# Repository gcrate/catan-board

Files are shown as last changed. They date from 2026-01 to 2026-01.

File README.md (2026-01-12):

# LED Catan Board

An interactive 3D-printed Catan board with LED-lit hexes controlled by a Raspberry Pi. When you roll the dice, the matching resource hexes light up!

Roll
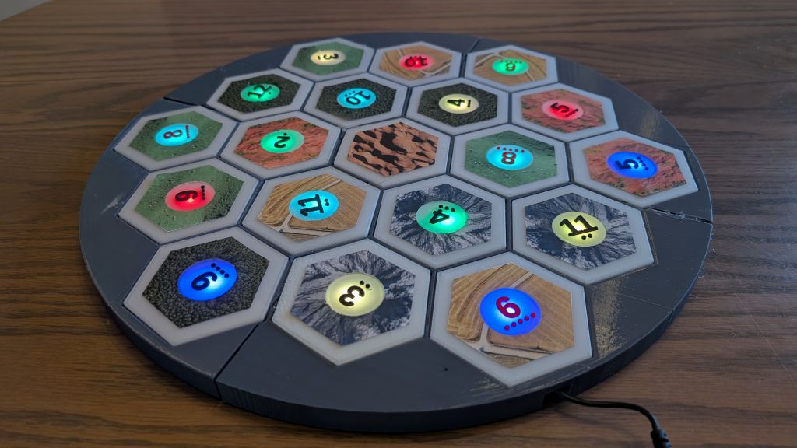
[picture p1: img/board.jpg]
Catan Board

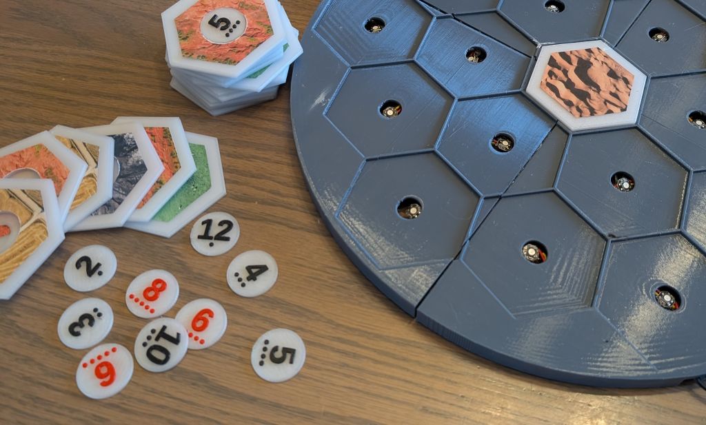
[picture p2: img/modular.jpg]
Catan Tiles


## Features

- **19 hex tiles** with satellite imagery stickers
- **18 addressable LEDs** (one per resource hex, desert has no LED)
- **Web-based controller** - access via phone or computer
- **Randomize board** with standard Catan rules
- **Auto or manual dice rolls** - matching tiles blink when rolled
- **Rainbow startup effect** until first randomization
- **Tap-to-test** individual LEDs during setup

## Hardware Required

| Item | Quantity | Notes |
|---|---|---|
| Raspberry Pi Zero W (or Zero 2 W) | 1 | Must have WiFi |
| WS2812B LED pixel modules | 18 | Individual addressable pixels with JST connectors |
| Micro SD card | 1 | 8GB+ recommended |
| USB power bank | 1 | 2A+ output recommended |
| Low Profile Micro USB cable | 1 | For powering the Pi |
| Wire | ~2m | 22-24 AWG, stranded or solid core |
| 3D printer filament | ~500g | PLA for frame and tiles |
| Clear/translucent PLA | ~50g | For number tokens |
| Printable sticker paper | 2 sheets | For hex tile imagery |

## 3D Printed Parts

All models are in the `/models` folder.

### Board (`board.3mf / board-rounded.stl`)

The main board frame with:
- 19 hex recesses for tiles
- 18 LED holes (15mm diameter) in the ledges between hexes
- Wire tunnels connecting all hexes
- Pi Zero W mounting standoffs in center
- USB cable channel

**Print Settings:**
- The full board is ~471mm diameter - too large for most printer
- board.3mf provides pre sliced / quatered board for printing on p1p/p1s
- Glue together after printing

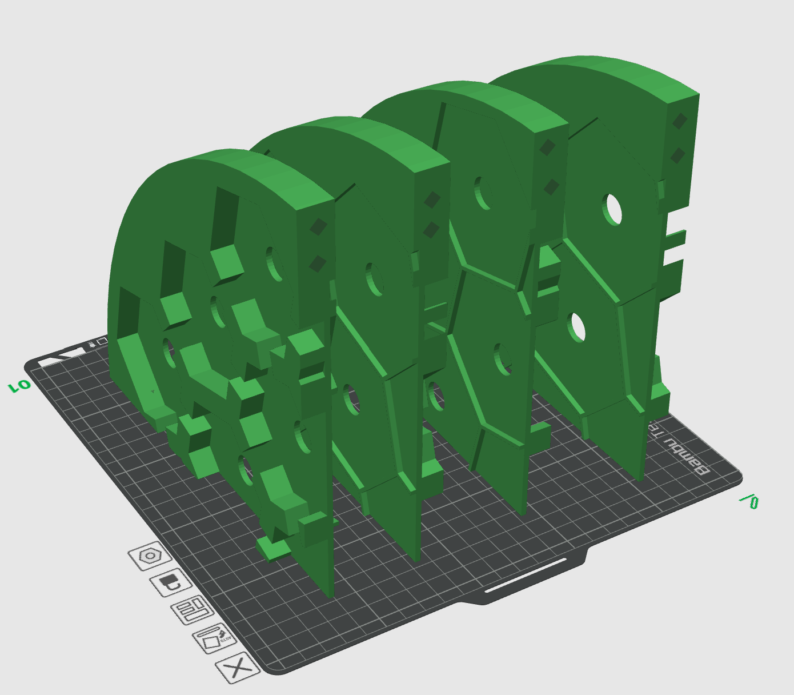
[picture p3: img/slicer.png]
In Slicer


### Hex Tiles - Desert (`tile-desert.stl`)

Central desert time, can be glued in place to hold board together

### Hex Tiles - Resources (`tile.stl`)

Print 18 resource tiles:
- 75mm flat-to-flat
- 3mm thick
- 15mm center hole for LED light
- 30mm recess for number token

### Number Tokens (`all_tokens.3mf`)

Print in clear/translucent PLA:
- 29.5mm diameter
- Raised numbers and probability dots
- Standard Catan distribution: 2, 3, 3, 4, 4, 5, 5, 6, 6, 8, 8, 9, 9, 10, 10, 11, 11, 12

## Stickers

The `/stickers` folder contains an HTML template for printing hex stickers.

1. Find satellite imagery for each resource type:
   - **Brick:** Red rock formations, clay quarries
   - **Wood:** Dense forest canopy from above
   - **Sheep:** Green pastures with sheep visible
   - **Wheat:** Golden crop fields
   - **Ore:** Mountain peaks, rocky terrain
   - **Desert:** Sand dunes

2. You can replace the images if you want to change the look `brick.jpg`, `wood.jpg`, `sheep.jpg`, `wheat.jpg`, `ore.jpg`, `desert.jpg`

3. Open `sticker-template.html` in a browser

4. Print on sticker paper at actual size (73mm hexes)

5. Cut out and apply to tiles

## Wiring

### LED Order

Wire the 18 LEDs in series, starting from the inner ring and going counter-clockwise (when looking at the bottom): 

- **Ring 1 (inner):** LED 0-5
- **Ring 2 (outer):** LED 6-17

### Connections

| LED Wire | Pi Connection |
|---|---|
| VCC (5V) | Pin 2 or 4 (5V) |
| GND | Pin 6 (Ground) |
| DIN (Data) | GPIO12 (Pin 32) |

Chain the LEDs: Pi GPIO12 → LED 0 DIN → LED 0 DOUT → LED 1 DIN → ... → LED 17

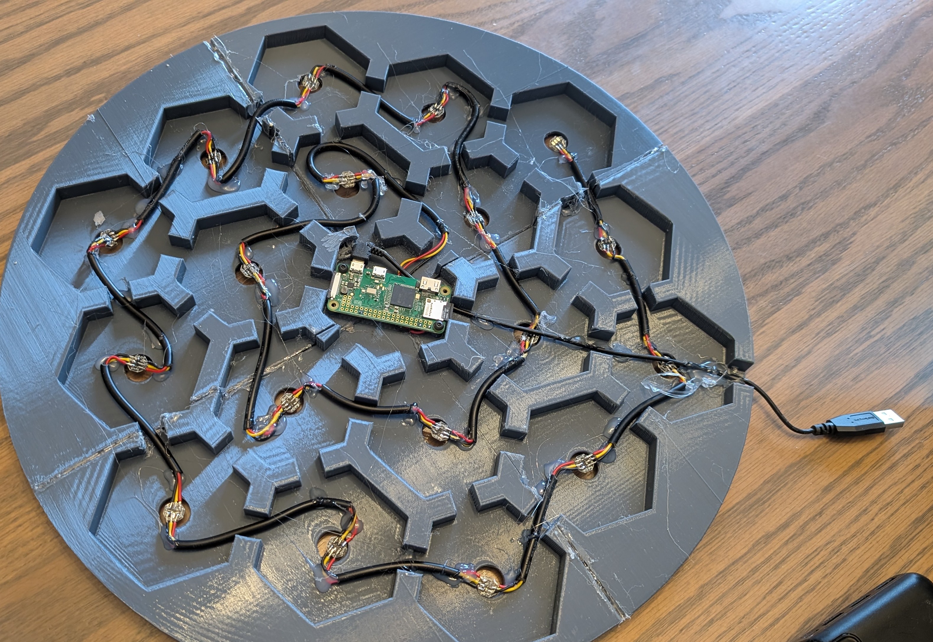
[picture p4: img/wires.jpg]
wiring


Hot glue gun the wires in place so the LEDs sit inline with the holes

## Software Setup

### 1. Flash Raspberry Pi OS

1. Download [Raspberry Pi Imager](https://www.raspberrypi.com/software/)
2. Select **Raspberry Pi OS Lite (32-bit)** under "Raspberry Pi OS (other)"
3. Click the gear icon and configure:
   - Hostname: `catan`
   - Enable SSH
   - Set username/password
   - Configure WiFi
4. Flash to SD card

### 2. Install Dependencies

SSH into your Pi:

```bash
ssh pi@catan.local
```

Update and install packages:

```bash
sudo apt update
sudo apt install -y python3-pip python3-flask git
sudo pip3 install rpi_ws281x adafruit-circuitpython-neopixel --break-system-packages
```

### 3. Clone the Repository

```bash
cd ~
git clone https://github.com/gcrate/catan-board.git
cd catan-board
```

### 4. Create Systemd Service

```bash
sudo tee /etc/systemd/system/catanboard.service > /dev/null <<EOF
[Unit]
Description=Catan Board Web Server
After=network.target

[Service]
ExecStart=/usr/bin/python3 /home/pi/catan-board/app.py
WorkingDirectory=/home/pi/catan-board
StandardOutput=inherit
StandardError=inherit
Restart=always
User=root

[Install]
WantedBy=multi-user.target
EOF
```

**Note:** Change `/home/pi/` to `/home/yourusername/` if you used a different username.

### 5. Enable and Start

```bash
sudo systemctl daemon-reload
sudo systemctl enable catanboard
sudo systemctl start catanboard
```

### 6. Access the Web Interface

Open a browser and go to:
```
http://catan.local
```

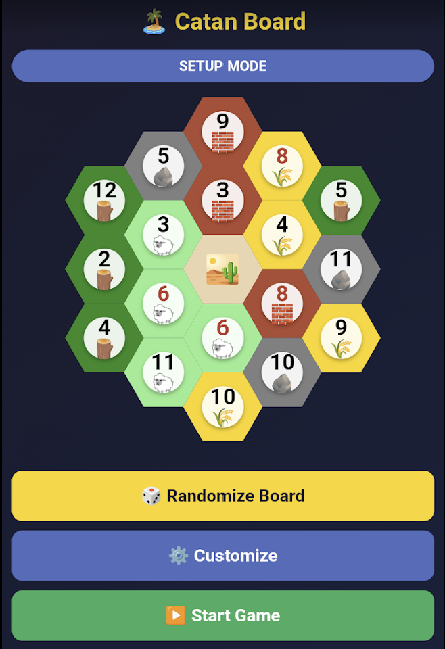
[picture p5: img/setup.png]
App setup mode

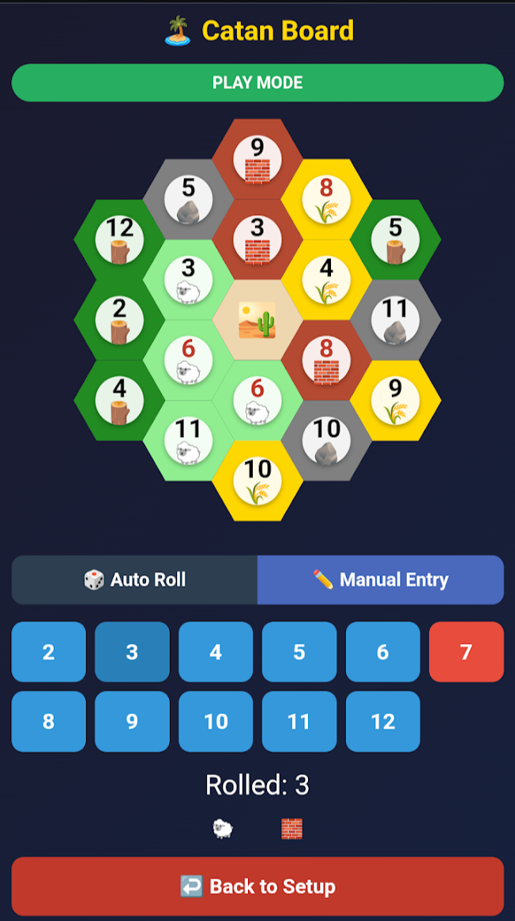
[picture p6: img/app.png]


## Usage

### Setup Mode

1. **Rainbow effect** plays on startup
2. Tap **Randomize Board** to generate a valid Catan layout
3. The LEDs will light up with resource colors
4. Tap any hex to flash that LED (for testing)
5. Use **Customize** to adjust resource counts or enable "prevent adjacent 6 & 8"
6. Tap **Start Game** when ready

### Play Mode

Two options for dice rolls:

**Auto Roll:**
- Tap **Roll Dice** to simulate 2d6
- Matching hexes will blink

**Manual Entry:**
- Tap a number button (2-12)
- Use this when rolling physical dice

Tap **Back to Setup** to randomize a new board.

## Troubleshooting

### LEDs not working

1. Check GPIO pin - code uses GPIO12 (Pin 32)
2. Verify ground is connected between Pi and LEDs
3. Make sure data wire goes to DIN (data in), not DOUT
4. Test with a simple script:

```python
import board
import neopixel
pixels = neopixel.NeoPixel(board.D12, 18, brightness=0.5)
pixels.fill((255, 0, 0))  # All red
```

### Web interface not loading

```bash
sudo systemctl status catanboard
sudo journalctl -u catanboard -n 50
```

### Wrong LEDs lighting up

The LED index must match the wiring order. Use setup mode's tap-to-flash feature to verify each position.

## Optional: Hotspot Mode

To use the board without a WiFi network, configure the Pi as a hotspot:

```bash
sudo apt install -y hostapd dnsmasq
```

See [Raspberry Pi hotspot documentation](https://www.raspberrypi.com/documentation/computers/configuration.html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) for full setup.

## TODO: 

Need to add some stickers for the ports. Using the cardboard ones that come with the game for now

## License

MIT License - feel free to build your own and modify!

## Acknowledgments

This was a quick weekend project - thanks to Claude AI!

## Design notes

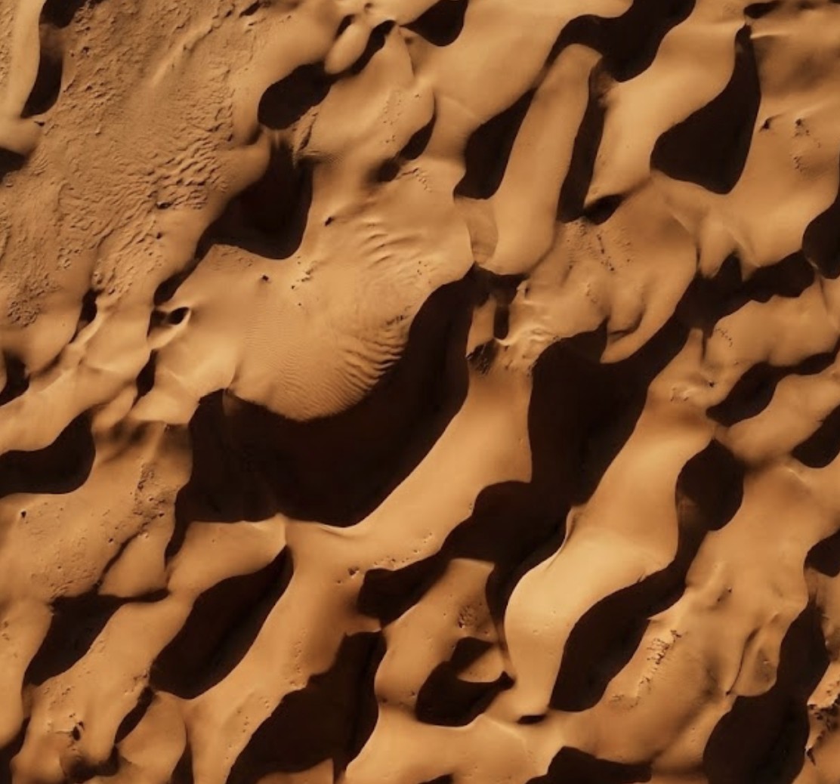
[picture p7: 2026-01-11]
stickers/desert.jpg

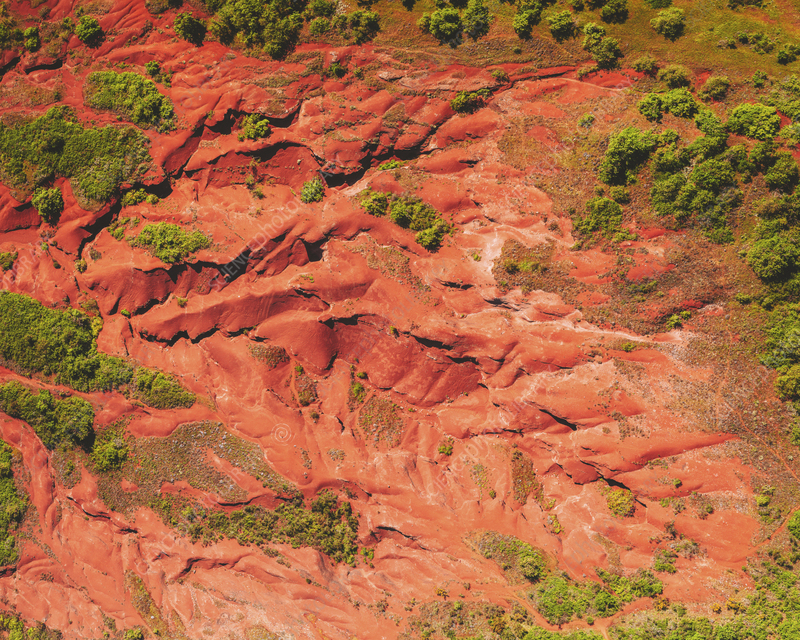
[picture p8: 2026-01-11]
stickers/brick.jpg

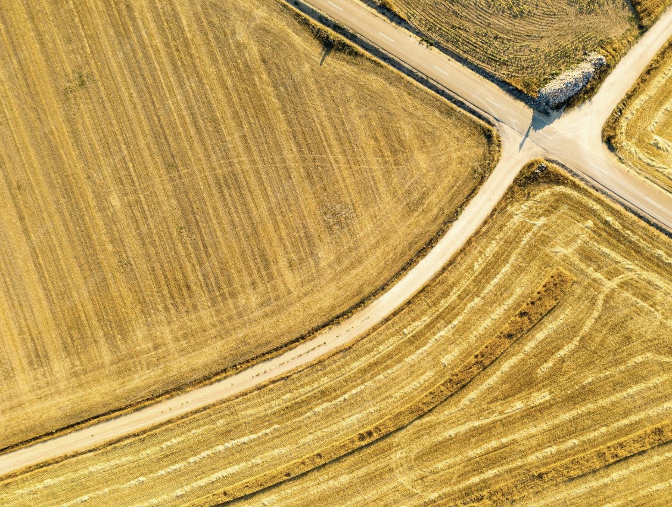
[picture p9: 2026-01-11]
stickers/wheat.jpg

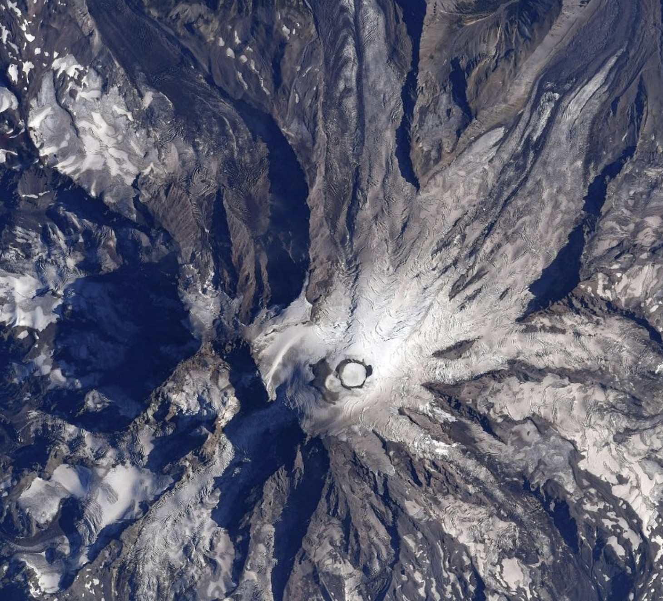
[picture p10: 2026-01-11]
stickers/ore.jpg

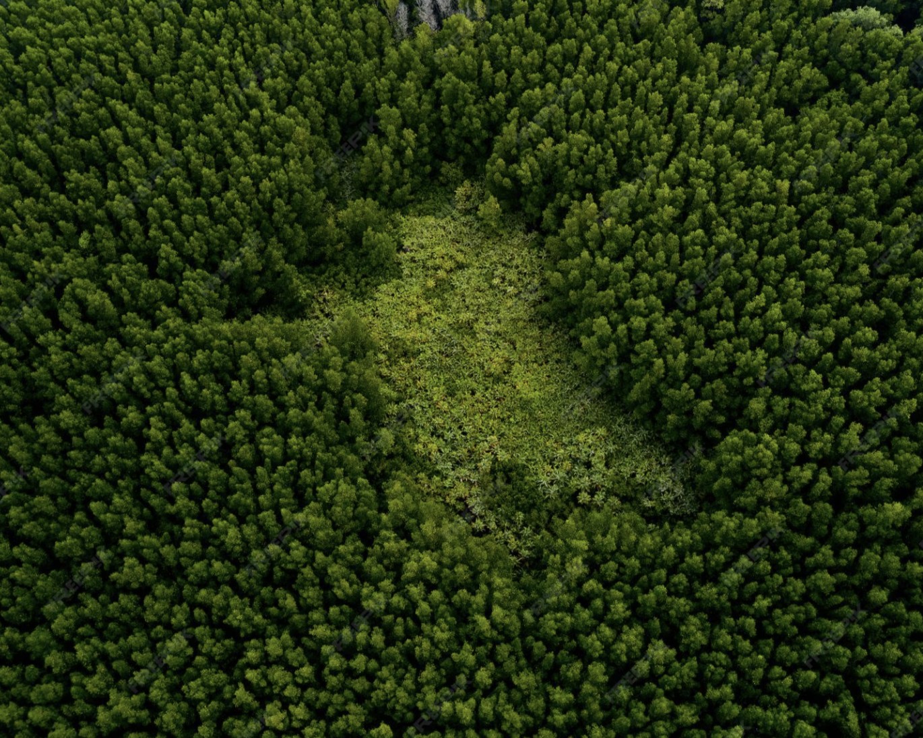
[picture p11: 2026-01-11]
stickers/wood.jpg

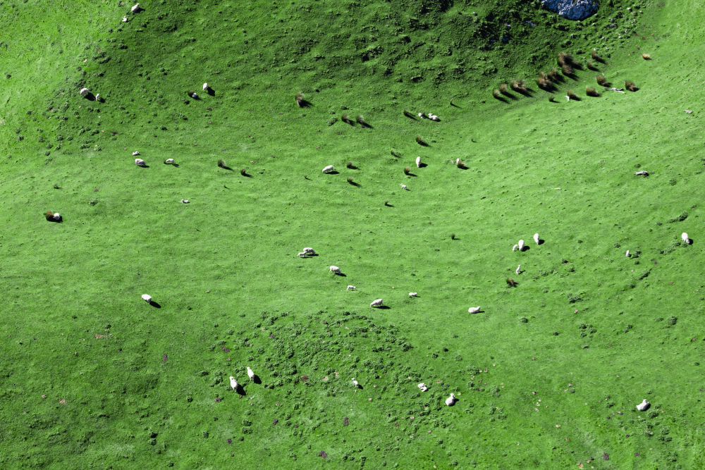
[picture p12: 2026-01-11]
stickers/sheep.jpg

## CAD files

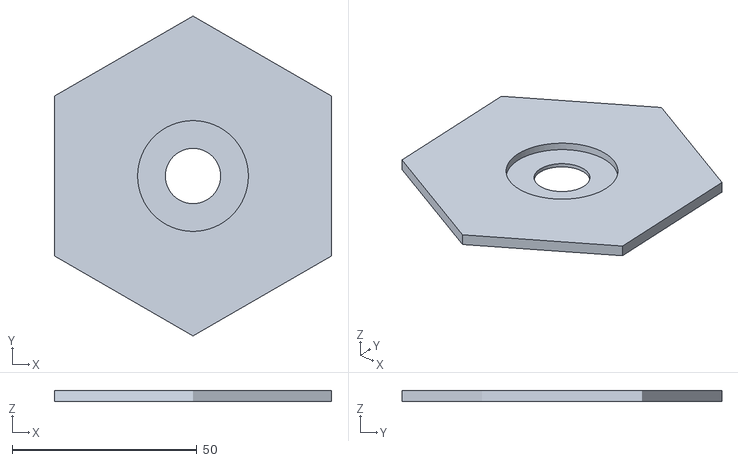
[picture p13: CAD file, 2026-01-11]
models/tile.stl
75.0 x 86.6 x 3.00

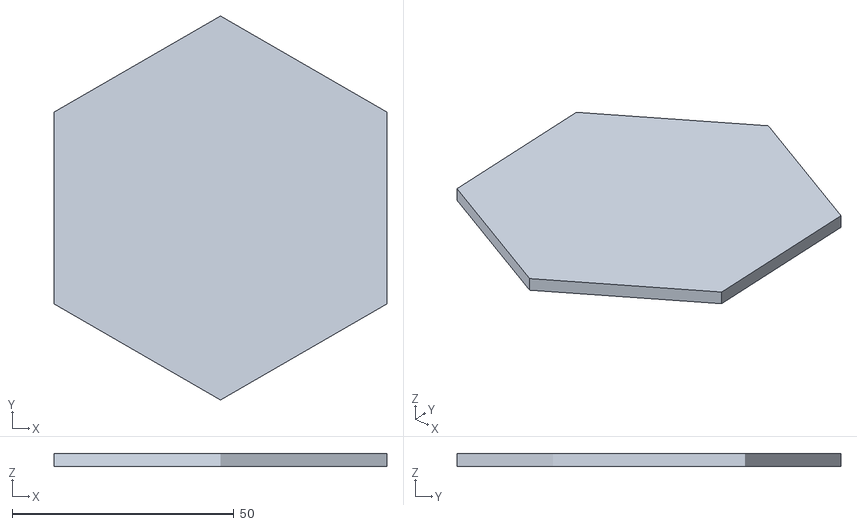
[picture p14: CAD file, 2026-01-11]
models/tile-desert.stl
75.0 x 86.6 x 3.00

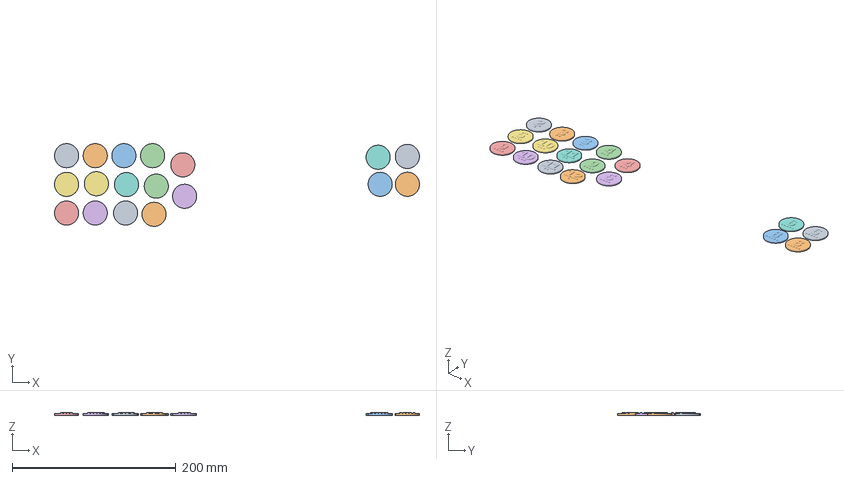
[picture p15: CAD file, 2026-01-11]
models/all_tokens.3mf
445.7 x 101.1 x 3.20 mm
all_tokens.stl_1
all_tokens.stl_2
all_tokens.stl_3
all_tokens.stl_4
all_tokens.stl_5
all_tokens.stl_6
all_tokens.stl_7
all_tokens.stl_8
all_tokens.stl_9
all_tokens.stl_10
all_tokens.stl_11
all_tokens.stl_12
all_tokens.stl_13
all_tokens.stl_14
all_tokens.stl_15
all_tokens.stl_16
all_tokens.stl_17
all_tokens.stl_18

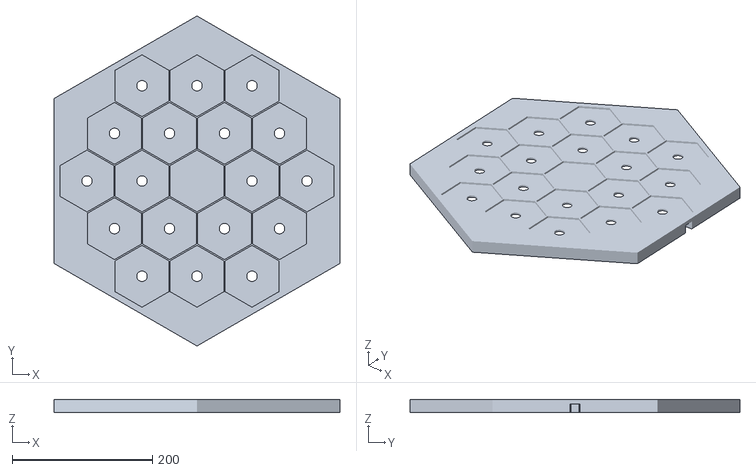
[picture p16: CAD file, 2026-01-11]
models/board-original.stl
407.9 x 471.0 x 18.0

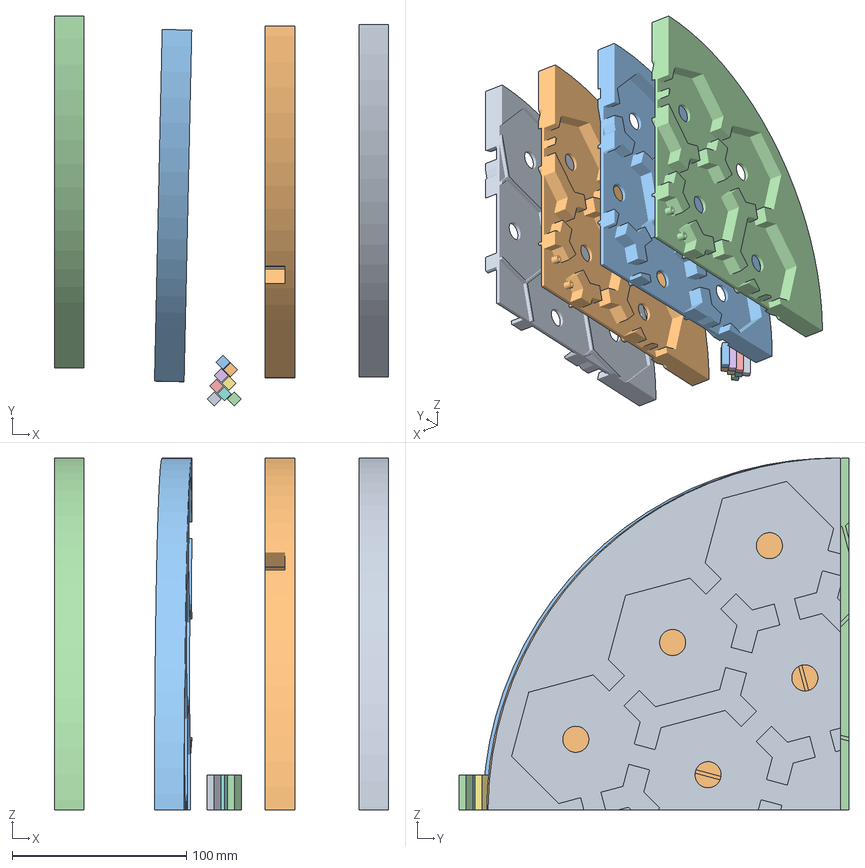
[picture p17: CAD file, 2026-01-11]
models/board.3mf
191.7 x 223.6 x 201.8 mm
Epic Allis-Wluff.stl_A_B
Epic Allis-Wluff.stl_A_A
Epic Allis-Wluff.stl_B_B
Epic Allis-Wluff.stl_B_A
Epic Allis-Wluff.stl_A-Dowel-Connector-7
Epic Allis-Wluff.stl_A-Dowel-Connector-8
Epic Allis-Wluff.stl-Dowel-Connector-1
Epic Allis-Wluff.stl-Dowel-Connector-2
Epic Allis-Wluff.stl-Dowel-Connector-3
Epic Allis-Wluff.stl-Dowel-Connector-4
Epic Allis-Wluff.stl_B-Dowel-Connector-5
Epic Allis-Wluff.stl_B-Dowel-Connector-6

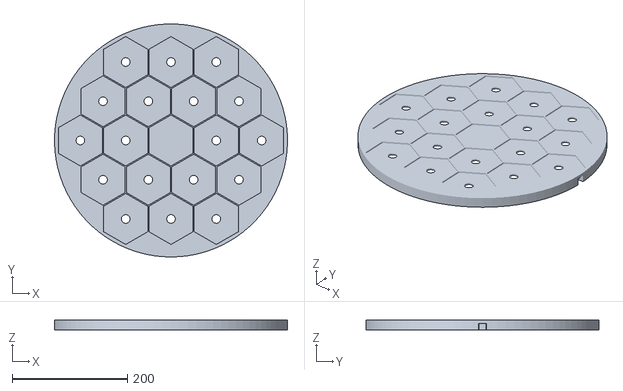
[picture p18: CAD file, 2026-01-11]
models/board-rounded.stl
403.7 x 403.6 x 17.0

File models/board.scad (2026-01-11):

// Catan Board Parameters
hex_flat_to_flat = 75;
tile_tolerance = 1.5;
led_hole_diameter = 15;
frame_depth = 18;
recess_depth = 3;
ledge_thickness = 3;
ledge_width = 6;

// Wire tunnel parameters
tunnel_width = 12;

// USB channel parameters
usb_channel_width = 14;
usb_channel_height = 12;

// Pi Zero W mounting parameters
pi_hole_spacing_x = 58;
pi_hole_spacing_y = 23;
pi_standoff_diameter = 6;
pi_screw_hole_diameter = 2.5;
pi_standoff_height = 6;

// Derived values
hex_radius = (hex_flat_to_flat + tile_tolerance) / 2 / cos(30);
cavity_radius = hex_radius - ledge_width;
cavity_depth = frame_depth - recess_depth - ledge_thickness;
hex_spacing = hex_flat_to_flat + tile_tolerance + 2;
outer_radius = hex_spacing * 3;

// Cut for a single hex with LED hole
module hex_cut_base() {
    rotate([0, 0, 30]) {
        translate([0, 0, frame_depth - recess_depth])
            cylinder(r = hex_radius, h = recess_depth + 1, $fn = 6);
        translate([0, 0, -1])
            cylinder(r = cavity_radius, h = cavity_depth + 1, $fn = 6);
        translate([0, 0, cavity_depth - 1])
            cylinder(d = led_hole_diameter, h = ledge_thickness + 2, $fn = 32);
    }
}

// Center hex - no LED hole, Pi goes here
module center_hex_cut() {
    rotate([0, 0, 30]) {
        translate([0, 0, frame_depth - recess_depth])
            cylinder(r = hex_radius, h = recess_depth + 1, $fn = 6);
        translate([0, 0, -1])
            cylinder(r = cavity_radius, h = cavity_depth + 1, $fn = 6);
    }
}

// Pi mounting standoff
module pi_standoff() {
    difference() {
        cylinder(d = pi_standoff_diameter, h = pi_standoff_height, $fn = 32);
        translate([0, 0, -1])
            cylinder(d = pi_screw_hole_diameter, h = pi_standoff_height + 2, $fn = 32);
    }
}

module pi_standoffs() {
    for (x = [-pi_hole_spacing_x/2, pi_hole_spacing_x/2]) {
        for (y = [-pi_hole_spacing_y/2, pi_hole_spacing_y/2]) {
            translate([x, y, cavity_depth - pi_standoff_height])
                pi_standoff();
        }
    }
}

// USB channel
module usb_channel() {
    translate([0, -usb_channel_width/2, -1])
        cube([hex_spacing * 3, usb_channel_width, usb_channel_height + 1]);
}

// Tunnel cut between two hexes
module tunnel_cut(from_q, from_r, to_q, to_r) {
    from_x = hex_spacing * (from_q + from_r/2);
    from_y = hex_spacing * from_r * sin(60);
    to_x = hex_spacing * (to_q + to_r/2);
    to_y = hex_spacing * to_r * sin(60);
    mid_x = (from_x + to_x) / 2;
    mid_y = (from_y + to_y) / 2;
    angle = atan2(to_y - from_y, to_x - from_x);
    translate([mid_x, mid_y, -1])
        rotate([0, 0, angle])
        translate([-10, -tunnel_width/2, 0])
            cube([20, tunnel_width, cavity_depth + 1]);
}

module place_hex_cut(q, r) {
    x = hex_spacing * (q + r/2);
    y = hex_spacing * r * sin(60);
    translate([x, y, 0])
        hex_cut_base();
}

// Base plate
module base_plate() {
    rotate([0, 0, 30])
    cylinder(r = outer_radius, h = frame_depth, $fn = 6);
}

// Full board
module full_board() {
    union() {
        difference() {
            base_plate();
            center_hex_cut();
            usb_channel();
            
            // Ring 1
            place_hex_cut(1, 0);
            place_hex_cut(0, 1);
            place_hex_cut(-1, 1);
            place_hex_cut(-1, 0);
            place_hex_cut(0, -1);
            place_hex_cut(1, -1);
            
            // Ring 2
            place_hex_cut(2, 0);
            place_hex_cut(1, 1);
            place_hex_cut(0, 2);
            place_hex_cut(-1, 2);
            place_hex_cut(-2, 2);
            place_hex_cut(-2, 1);
            place_hex_cut(-2, 0);
            place_hex_cut(-1, -1);
            place_hex_cut(0, -2);
            place_hex_cut(1, -2);
            place_hex_cut(2, -2);
            place_hex_cut(2, -1);
            
            // Tunnels - center to ring 1
            tunnel_cut(0, 0, 1, 0);
            tunnel_cut(0, 0, 0, 1);
            tunnel_cut(0, 0, -1, 1);
            tunnel_cut(0, 0, -1, 0);
            tunnel_cut(0, 0, 0, -1);
            tunnel_cut(0, 0, 1, -1);
            
            // Tunnels - ring 1 around
            tunnel_cut(1, 0, 0, 1);
            tunnel_cut(0, 1, -1, 1);
            tunnel_cut(-1, 1, -1, 0);
            tunnel_cut(-1, 0, 0, -1);
            tunnel_cut(0, -1, 1, -1);
            tunnel_cut(1, -1, 1, 0);
            
            // Tunnels - ring 1 to ring 2
            tunnel_cut(1, 0, 2, 0);
            tunnel_cut(1, 0, 2, -1);
            tunnel_cut(0, 1, 1, 1);
            tunnel_cut(0, 1, 0, 2);
            tunnel_cut(-1, 1, -1, 2);
            tunnel_cut(-1, 1, -2, 2);
            tunnel_cut(-1, 0, -2, 1);
            tunnel_cut(-1, 0, -2, 0);
            tunnel_cut(0, -1, -1, -1);
            tunnel_cut(0, -1, 0, -2);
            tunnel_cut(1, -1, 1, -2);
            tunnel_cut(1, -1, 2, -2);
            
            // Tunnels - ring 2 around
            tunnel_cut(2, 0, 1, 1);
            tunnel_cut(1, 1, 0, 2);
            tunnel_cut(0, 2, -1, 2);
            tunnel_cut(-1, 2, -2, 2);
            tunnel_cut(-2, 2, -2, 1);
            tunnel_cut(-2, 1, -2, 0);
            tunnel_cut(-2, 0, -1, -1);
            tunnel_cut(-1, -1, 0, -2);
            tunnel_cut(0, -2, 1, -2);
            tunnel_cut(1, -2, 2, -2);
            tunnel_cut(2, -2, 2, -1);
            tunnel_cut(2, -1, 2, 0);
        }
        pi_standoffs();
    }
}

full_board();

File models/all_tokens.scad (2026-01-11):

// Catan Number Tokens - All tokens for a standard game
// Print in clear/translucent PLA
// Standard set: 2, 3, 3, 4, 4, 5, 5, 6, 6, 8, 8, 9, 9, 10, 10, 11, 11, 12

// Token parameters
token_diameter = 29.5;
token_thickness = 2;
number_height = 1.2;  // How high the number is raised
number_size = 14;

// Layout
spacing = 35;

// Probability dots
function get_dots(n) = 
    (n == 2 || n == 12) ? 1 :
    (n == 3 || n == 11) ? 2 :
    (n == 4 || n == 10) ? 3 :
    (n == 5 || n == 9) ? 4 :
    (n == 6 || n == 8) ? 5 : 0;

dot_diameter = 2.5;
dot_spacing = 4;
dot_y_offset = -8;

module number_token(number) {
    // Base token
    cylinder(d = token_diameter, h = token_thickness, $fn = 64);
    
    // Raised number
    translate([0, 2, token_thickness])
        linear_extrude(height = number_height)
            text(str(number), size = number_size, font = "Liberation Sans:style=Bold", halign = "center", valign = "center");
    
    // Raised dots
    num_dots = get_dots(number);
    if (num_dots > 0) {
        start_x = -(num_dots - 1) * dot_spacing / 2;
        for (i = [0:num_dots-1]) {
            translate([start_x + i * dot_spacing, dot_y_offset, token_thickness])
                cylinder(d = dot_diameter, h = number_height, $fn = 16);
        }
    }
}

// Standard Catan number distribution
numbers = [2, 3, 3, 4, 4, 5, 5, 6, 6, 8, 8, 9, 9, 10, 10, 11, 11, 12];

// Arrange in a grid (6 columns)
cols = 6;
for (i = [0:len(numbers)-1]) {
    row = floor(i / cols);
    col = i % cols;
    translate([col * spacing, -row * spacing, 0])
        number_token(numbers[i]);
}

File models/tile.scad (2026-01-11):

// Catan Hex Tile
// Designed for sticker top and translucent number token

// Tile parameters - should match frame recess
tile_flat_to_flat = 75;
tile_thickness = 3;

// Light hole parameters
light_hole_diameter = 15;

// Token recess parameters
token_diameter = 30;
token_recess_depth = 2;

// Derived values
tile_radius = tile_flat_to_flat / 2 / cos(30);

module hex_tile() {
    difference() {
        // Main hex body
        rotate([0, 0, 30])
            cylinder(r = tile_radius, h = tile_thickness, $fn = 6);
        
        // Light hole through center
        translate([0, 0, -1])
            cylinder(d = light_hole_diameter, h = tile_thickness + 2, $fn = 32);
        
        // Token recess on top
        translate([0, 0, tile_thickness - token_recess_depth])
            cylinder(d = token_diameter, h = token_recess_depth + 1, $fn = 64);
    }
}

hex_tile();

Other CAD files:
models/all_tokens.stl

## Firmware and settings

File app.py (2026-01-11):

from flask import Flask, render_template, jsonify, request
import random
import json
import threading
import time

app = Flask(__name__)

# LED control - will be replaced with real implementation when hardware is ready
LED_ENABLED = True
pixels = None

if LED_ENABLED:
    import board
    import neopixel
    pixels = neopixel.NeoPixel(board.D12, 18, brightness=0.5, auto_write=False)

# Resource colors (RGB)
RESOURCE_COLORS = {
    'brick': (130, 3, 3),      # Brownish red
    'wood': (0, 120, 0),        # Dark green
    'sheep': (0, 100, 30),    # Light green
    'wheat': (130, 85, 0),      # Gold
    'ore': (10, 10, 128),      # Gray
    'desert': (0, 0, 0)          # No light for desert (always center, no LED)
}

# Standard Catan resource distribution (18 resources + 1 desert in center = 19)
# Desert is always in center (index 0) and has no LED
STANDARD_RESOURCES = {
    'brick': 3,
    'wood': 4,
    'sheep': 4,
    'wheat': 4,
    'ore': 3
}
# Note: desert is not in this dict - it's always fixed at center

# Standard Catan number tokens (no 7, desert gets none)
STANDARD_NUMBERS = [2, 3, 3, 4, 4, 5, 5, 6, 6, 8, 8, 9, 9, 10, 10, 11, 11, 12]

# Hex positions (index corresponds to LED index)
# Adjacency map for checking 6/8 rule
ADJACENCIES = {
    0: [1, 2, 3, 4, 5, 6],      # Center connects to ring 1
    1: [0, 2, 6, 7, 8, 12],     # Ring 1
    2: [0, 1, 3, 8, 9, 10],
    3: [0, 2, 4, 10, 11, 12],
    4: [0, 3, 5, 12, 13, 14],
    5: [0, 4, 6, 14, 15, 16],
    6: [0, 1, 5, 16, 17, 7],
    7: [1, 6, 8, 17, 18, 12],   # Ring 2
    8: [1, 2, 7, 9, 18, 19],
    9: [2, 8, 10, 19, 20, 21],
    10: [2, 3, 9, 11, 21, 22],
    11: [3, 10, 12, 22, 23, 24],
    12: [1, 3, 4, 7, 11, 13],
    13: [4, 12, 14, 24, 25, 26],
    14: [4, 5, 13, 15, 26, 27],
    15: [5, 14, 16, 27, 28, 29],
    16: [5, 6, 15, 17, 29, 30],
    17: [6, 7, 16, 18, 30, 31],
    18: [7, 8, 17, 19, 31, 32]
}

# Simplified adjacency for 19-hex board (0 = center, 1-6 = ring 1, 7-18 = ring 2)
# Re-mapping to match actual 19 hexes
ADJACENCIES_19 = {
    0: [1, 2, 3, 4, 5, 6],           # Center
    1: [0, 2, 6, 7, 8, 12],          # Ring 1
    2: [0, 1, 3, 8, 9, 10],
    3: [0, 2, 4, 10, 11, 12],
    4: [0, 3, 5, 12, 13, 14],
    5: [0, 4, 6, 14, 15, 16],
    6: [0, 1, 5, 16, 17, 7],
    7: [1, 6, 17, 18],               # Ring 2 (corners have fewer neighbors)
    8: [1, 2, 9, 7],
    9: [2, 8, 10, 18],
    10: [2, 3, 9, 11],
    11: [3, 10, 12, 18],
    12: [3, 4, 11, 13],
    13: [4, 12, 14, 18],
    14: [4, 5, 13, 15],
    15: [5, 14, 16, 18],
    16: [5, 6, 15, 17],
    17: [6, 7, 16, 18],
    18: [7, 9, 11, 13, 15, 17]       # This doesn't exist in standard - we have 19 hexes 0-18
}

# Correct adjacency for 19 hexes (center=0, ring1=1-6, ring2=7-18)
HEX_ADJACENCIES = {
    0: [1, 2, 3, 4, 5, 6],
    1: [0, 2, 6, 7, 8, 9],
    2: [0, 1, 3, 9, 10, 11],
    3: [0, 2, 4, 11, 12, 13],
    4: [0, 3, 5, 13, 14, 15],
    5: [0, 4, 6, 15, 16, 17],
    6: [0, 1, 5, 17, 18, 7],
    7: [1, 6, 8, 18],
    8: [1, 7, 9],
    9: [1, 2, 8, 10],
    10: [2, 9, 11],
    11: [2, 3, 10, 12],
    12: [3, 11, 13],
    13: [3, 4, 12, 14],
    14: [4, 13, 15],
    15: [4, 5, 14, 16],
    16: [5, 15, 17],
    17: [5, 6, 16, 18],
    18: [6, 7, 17]
}

# Current board state
board_state = {
    'tiles': [],  # List of {resource, number, led_index}
    'mode': 'setup',  # 'setup' or 'play'
    'config': {
        'resources': STANDARD_RESOURCES.copy(),
        'numbers': STANDARD_NUMBERS.copy(),
        'prevent_adjacent_68': False
    }
}

# Track which LEDs are currently flashing
flashing_leds = set()

# Track rainbow animation state
rainbow_animation_running = False

# Track red flash state (for 7 rolls)
red_flash_in_progress = False


def get_rainbow_color(hue):
    """Convert hue (0-1) to RGB color"""
    # hue: 0=red, 0.166=yellow, 0.333=green, 0.5=cyan, 0.666=blue, 0.833=magenta, 1=red
    if hue < 0 or hue > 1:
        hue = hue % 1
    
    h = hue * 6
    c = 200  # Chroma (brightness)
    
    if h < 1:
        r, g, b = c, int(c * h), 0
    elif h < 2:
        r, g, b = int(c * (2 - h)), c, 0
    elif h < 3:
        r, g, b = 0, c, int(c * (h - 2))
    elif h < 4:
        r, g, b = 0, int(c * (4 - h)), c
    elif h < 5:
        r, g, b = int(c * (h - 4)), 0, c
    else:
        r, g, b = c, 0, int(c * (6 - h))
    
    return (int(r), int(g), int(b))


def rainbow_cycle_animation():
    """Cycle all LEDs through rainbow colors"""
    global rainbow_animation_running
    
    if not LED_ENABLED or pixels is None:
        return
    
    hue = 0
    while rainbow_animation_running:
        for i in range(18):
            pixels[i] = get_rainbow_color(hue + (i / 18.0))
        pixels.show()
        hue += 0.01  # Increment hue for smooth cycling
        time.sleep(0.05)  # Update every 50ms


def init_board():
    """Initialize board with empty tiles"""
    global rainbow_animation_running
    
    board_state['tiles'] = [
        {'resource': None, 'number': None, 'led_index': i}
        for i in range(19)
    ]
    
    # Start rainbow animation
    if LED_ENABLED and pixels is not None:
        rainbow_animation_running = True
        thread = threading.Thread(target=rainbow_cycle_animation, daemon=True)
        thread.start()


def check_adjacent_68(tiles):
    """Check if any 6 and 8 are adjacent"""
    for i, tile in enumerate(tiles):
        if tile['number'] in [6, 8]:
            for adj_idx in HEX_ADJACENCIES.get(i, []):
                if adj_idx < len(tiles) and tiles[adj_idx]['number'] in [6, 8]:
                    return True
    return False


def randomize_board(config, max_attempts=100):
    """Randomize the board with given configuration"""
    global rainbow_animation_running
    
    # Stop rainbow animation
    rainbow_animation_running = False
    time.sleep(0.1)  # Give animation thread time to stop
    
    resources = config['resources']
    numbers = config['numbers'].copy()
    prevent_68 = config['prevent_adjacent_68']

    # Build resource list for the 18 non-center tiles
    resource_list = []
    for resource, count in resources.items():
        resource_list.extend([resource] * count)

    # Verify we have exactly 18 resources
    if len(resource_list) != 18:
        raise ValueError(f"Resources must add up to 18, got {len(resource_list)}")

    # Shuffle resources
    random.shuffle(resource_list)

    # Create tiles - desert always at center (index 0), no LED there
    tiles = [{'resource': 'desert', 'number': None, 'led_index': None}]  # Center

    # Add the 18 resource tiles (indices 1-18, LED indices 0-17)
    for i in range(18):
        tiles.append({
            'resource': resource_list[i],
            'number': None,
            'led_index': i  # LED 0-17 maps to tile 1-18
        })

    # Assign numbers to non-desert tiles (indices 1-18)
    for attempt in range(max_attempts):
        random.shuffle(numbers)
        number_list = numbers.copy()

        for i in range(1, 19):
            tiles[i]['number'] = number_list.pop(0)

        # Check 6/8 adjacency if required
        if prevent_68 and check_adjacent_68(tiles):
            # Reset numbers and try again
            for i in range(1, 19):
                tiles[i]['number'] = None
            continue
        else:
            # Success
            break

    return tiles


def set_led_colors():
    """Update LED colors based on current board state"""
    if not LED_ENABLED or pixels is None:
        return

    for tile in board_state['tiles']:
        led_idx = tile['led_index']
        resource = tile['resource']
        # Skip desert (center) which has no LED
        if led_idx is not None and resource and resource != 'desert':
            color = RESOURCE_COLORS.get(resource, (0, 0, 0))
            pixels[led_idx] = color

    pixels.show()


def blink_tiles(number, times=10, on_time=0.3, off_time=0.2):
    """Blink tiles that match the rolled number"""
    if not LED_ENABLED or pixels is None:
        return

    matching_indices = [
        tile['led_index'] for tile in board_state['tiles']
        if tile['number'] == number and tile['led_index'] is not None
    ]

    # Store original colors
    original_colors = [pixels[i] for i in range(18)]

    for _ in range(times):
        # Turn on matching tiles bright white
        for led_idx in matching_indices:
            pixels[led_idx] = (255, 255, 255)
        pixels.show()
        time.sleep(on_time)

        # Return to resource colors
        for led_idx in matching_indices:
            # Find the tile with this LED index
            for tile in board_state['tiles']:
                if tile['led_index'] == led_idx:
                    resource = tile['resource']
                    pixels[led_idx] = RESOURCE_COLORS.get(resource, (0, 0, 0))
                    break
        pixels.show()
        time.sleep(off_time)


def flash_all_leds_red(times=5, on_time=0.3, off_time=0.2):
    """Flash all LEDs red and off (for rolling a 7)"""
    global red_flash_in_progress
    
    if not LED_ENABLED or pixels is None:
        return

    red_flash_in_progress = True
    try:
        # Store original colors
        original_colors = [pixels[i] for i in range(18)]

        for _ in range(times):
            # Turn all LEDs red
            for i in range(18):
                pixels[i] = (255, 0, 0)
            pixels.show()
            time.sleep(on_time)

            # Turn off
            for i in range(18):
                pixels[i] = (0, 0, 0)
            pixels.show()
            time.sleep(off_time)

        # Restore original colors
        for i in range(18):
            pixels[i] = original_colors[i]
        pixels.show()
    finally:
        red_flash_in_progress = False


# Routes
@app.route('/')
def index():
    return render_template('index.html')


@app.route('/api/state')
def get_state():
    return jsonify(board_state)


@app.route('/api/randomize', methods=['POST'])
def randomize():
    config = request.json if request.json else board_state['config']
    board_state['config'] = config
    board_state['tiles'] = randomize_board(config)
    board_state['mode'] = 'setup'
    set_led_colors()
    return jsonify(board_state)


@app.route('/api/start_game', methods=['POST'])
def start_game():
    board_state['mode'] = 'play'
    return jsonify(board_state)


@app.route('/api/back_to_setup', methods=['POST'])
def back_to_setup():
    board_state['mode'] = 'setup'
    return jsonify(board_state)


@app.route('/api/roll', methods=['POST'])
def roll_dice():
    global red_flash_in_progress
    
    # Ignore rolls if red flash is in progress
    if red_flash_in_progress:
        return jsonify({'error': 'Red flash in progress, please wait'}), 409
    
    data = request.json

    if data.get('auto'):
        # Simulate 2d6
        die1 = random.randint(1, 6)
        die2 = random.randint(1, 6)
        total = die1 + die2
    else:
        total = data.get('value')
        if not total or total < 2 or total > 12:
            return jsonify({'error': 'Invalid roll value'}), 400
        die1 = None
        die2 = None

    # Find matching tiles - use enumerate to get the actual tile index for UI highlighting
    matching = [
        {'index': idx, 'resource': tile['resource']}
        for idx, tile in enumerate(board_state['tiles'])
        if tile['number'] == total
    ]

    # Flash LEDs in background thread
    if LED_ENABLED:
        if total == 7:
            # Flash all LEDs red for a 7
            thread = threading.Thread(target=flash_all_leds_red)
        else:
            # Blink matching number tiles
            thread = threading.Thread(target=blink_tiles, args=(total,))
        thread.start()

    return jsonify({
        'die1': die1,
        'die2': die2,
        'total': total,
        'matching': matching
    })


@app.route('/api/config', methods=['GET', 'POST'])
def config():
    if request.method == 'POST':
        new_config = request.json

        # Validate resources add up to 18 (desert is always in center, not counted)
        total_tiles = sum(new_config.get('resources', {}).values())
        if total_tiles != 18:
            return jsonify({'error': f'Resources must add up to 18, got {total_tiles}'}), 400

        board_state['config'] = new_config
        return jsonify(board_state['config'])
    else:
        return jsonify(board_state['config'])


@app.route('/api/flash_led', methods=['POST'])
def flash_led():
    """Flash a single LED for testing during setup"""
    # Ignore flash commands if red flash is in progress
    if red_flash_in_progress:
        return jsonify({'status': 'red_flash_in_progress', 'message': 'Red flash in progress, please wait'}), 409
    
    data = request.json
    tile_index = data.get('tile_index')

    if tile_index is None or tile_index < 0 or tile_index >= 19:
        return jsonify({'error': 'Invalid tile index'}), 400

    # Get the LED index for this tile
    tile = board_state['tiles'][tile_index] if board_state['tiles'] else None
    led_index = tile.get('led_index') if tile else None

    # Desert (center) has no LED
    if led_index is None:
        return jsonify({'status': 'no_led', 'message': 'This tile has no LED (desert)'})

    # Check if this LED is already flashing
    if led_index in flashing_leds:
        return jsonify({'status': 'already_flashing', 'message': 'This LED is already flashing'}), 409

    # Flash the LED in background thread
    if LED_ENABLED and pixels is not None:
        def flash_single_led():
            flashing_leds.add(led_index)
            try:
                original_color = pixels[led_index]
                for _ in range(3):
                    pixels[led_index] = (255, 255, 255)
                    pixels.show()
                    time.sleep(0.2)
                    pixels[led_index] = original_color
                    pixels.show()
                    time.sleep(0.15)
            finally:
                flashing_leds.discard(led_index)

        thread = threading.Thread(target=flash_single_led)
        thread.start()
    else:
        # Even without hardware, track the flashing state
        flashing_leds.add(led_index)
        def flash_without_hardware():
            try:
                time.sleep(0.2 * 3 + 0.15 * 3)
            finally:
                flashing_leds.discard(led_index)
        thread = threading.Thread(target=flash_without_hardware)
        thread.start()

    return jsonify({'status': 'ok', 'tile_index': tile_index, 'led_index': led_index})


@app.route('/api/colors')
def get_colors():
    return jsonify(RESOURCE_COLORS)


# Initialize on startup
init_board()

if __name__ == '__main__':
    app.run(host='0.0.0.0', port=80, debug=False)
